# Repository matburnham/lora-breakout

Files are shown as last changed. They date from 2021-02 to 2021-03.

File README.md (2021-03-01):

# DRF1278F and XL1278-SMT LoRa breakout board

A somewhat 'universal' breakout board to adapt Dorji DRF1278F and XL1278-SMT modules to standard 0.1" matrix breadboard or stripboard format.

# Module identification

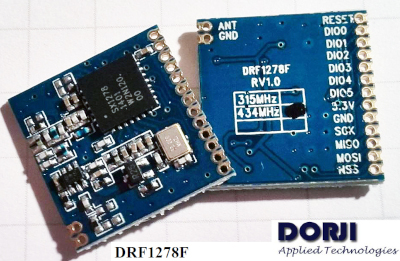
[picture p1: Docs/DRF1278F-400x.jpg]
DRF1278F


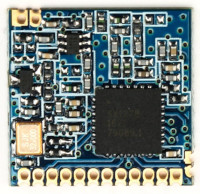
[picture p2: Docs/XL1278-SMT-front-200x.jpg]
XL1278-SMT-front
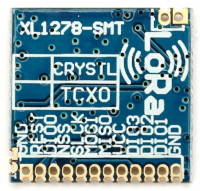
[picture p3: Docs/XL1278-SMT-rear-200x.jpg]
XL1278-SMT-back
 

Note: while the DRF1278F and XL1278-SMT boards look similar, the pinouts are significantly different.

## Confusion

There is a lot of confusion between Ebay and AliExpress sellers alike. One ebay seller even showing photos of both types of boards on the same listing. So check carefully, or use what you're given with this either/or breakout.

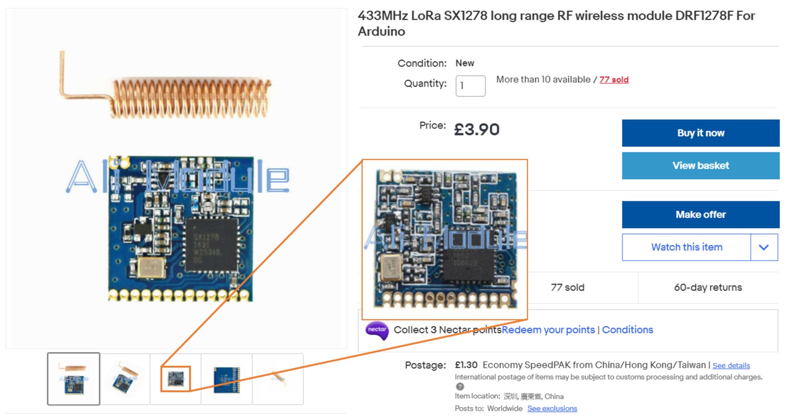
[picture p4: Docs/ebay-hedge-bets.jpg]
Ebay screenshot


## Documentation

CI/CD documentation generation 

TODO: links to generated documentation, etc.

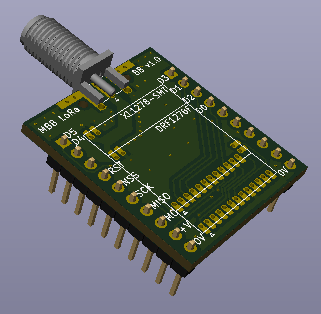
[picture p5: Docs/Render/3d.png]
3D render

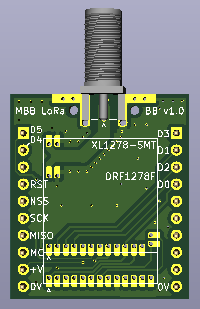
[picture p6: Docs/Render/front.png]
Front render

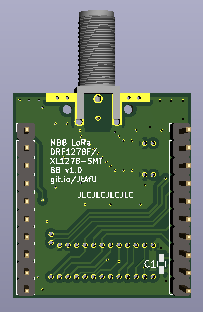
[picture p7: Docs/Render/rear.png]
Rear render


# Libraries

* KiCad symbol and footprint libraries for DRF1278F and XL1278-SMT for KiCad are at [kicad-libs](https://github.com/matburnham/kicad-libs)

# References

* Inspired by Stuart Robinson's Breadboard Friendly DRF1278 Board [Tindie](https://www.tindie.com/products/stuartsprojects/breadboard-friendly-board-for-dorji-drf1278-module/) | [GitHub](https://github.com/StuartsProjects/Devices/tree/master/Breadboard%20Friendly%20DRF1278%20Board)

* [Dorji DRF1278F datasheet](http://www.dorji.com/docs/data/DRF1278F.pdf) | [respository copy](Docs/DRF1278F.pdf)
* Closest information to a [XL1278-SMT datasheet](http://www.hr-wt.com/html_products/XL1278-SMT-59.html) | [respository screenshot](Docs/screencapture-hr-wt-html-products-XL1278-SMT-59-html-2021-02-26-15_49_33.png)

* [A Review of the Mini SX1278 LoRa Transceiver Module](https://www.electroschematics.com/rf-radio-frequency/)

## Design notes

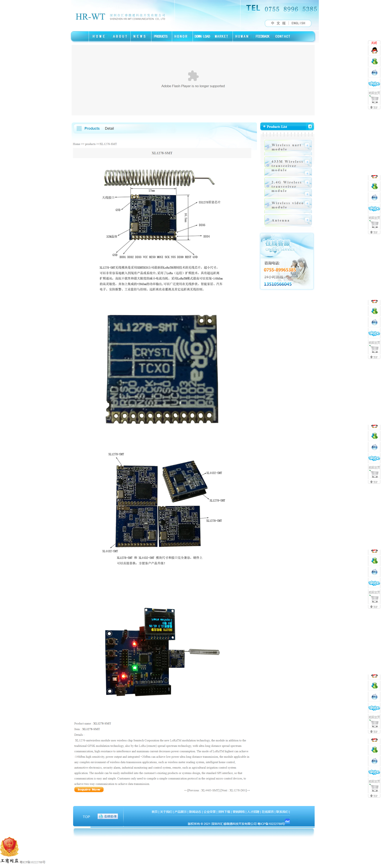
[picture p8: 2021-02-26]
Docs/screencapture-hr-wt-html-products-XL1278-SMT-59-html-2021-02-26-15_49_33.png

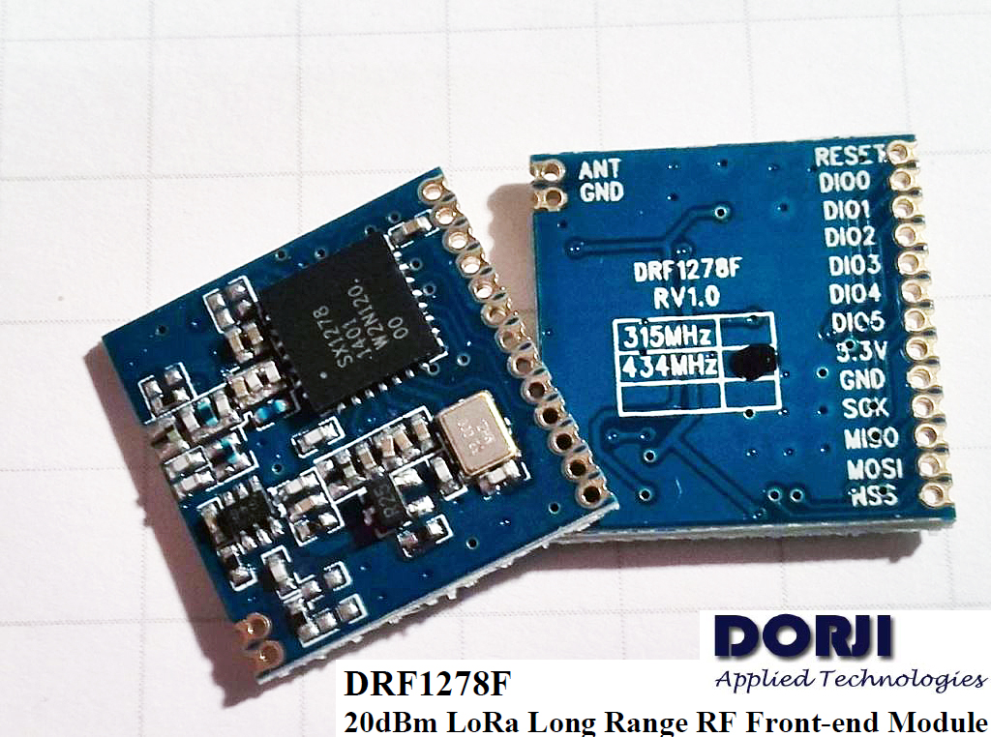
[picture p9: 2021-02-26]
Docs/DRF1278F.jpg

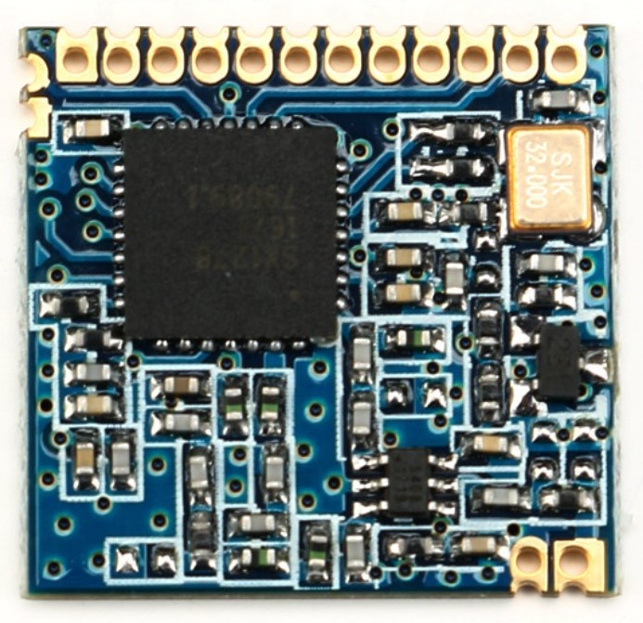
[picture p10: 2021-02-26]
Docs/XL1278-SMT-front.jpg

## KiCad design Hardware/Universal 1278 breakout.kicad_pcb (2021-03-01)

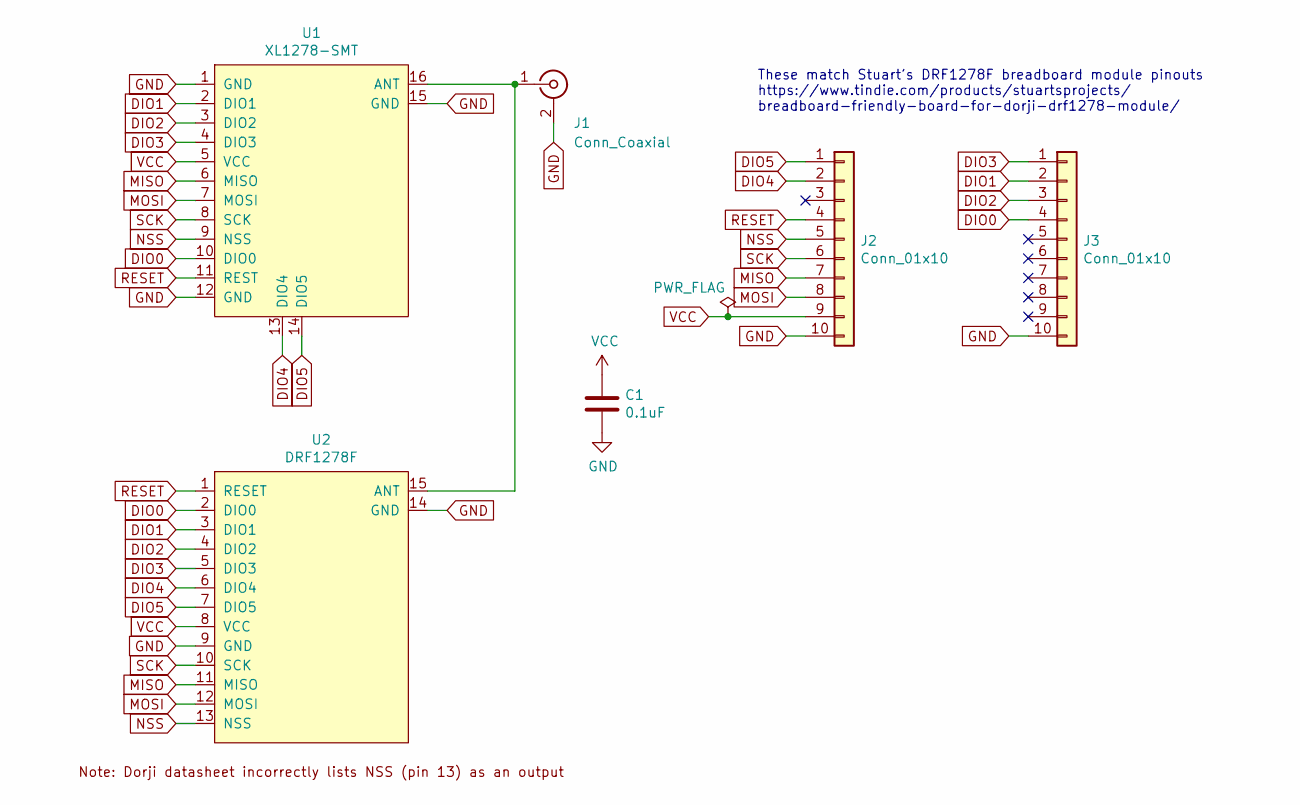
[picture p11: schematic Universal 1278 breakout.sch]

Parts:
C1: 0.1uF; C_0603_HandSoldering
J1: Conn_Coaxial; SMA_EdgeMount_Holes
J2, J3: Conn_01x10; PinHeader_1x10_P2.54mm_Vertical
U1: XL1278-SMT
U2: DRF1278F

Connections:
DIO0: J3.4, U1.10 (DIO0), U2.2 (DIO0)
DIO1: J3.2, U1.2 (DIO1), U2.3 (DIO1)
DIO2: J3.3, U1.3 (DIO2), U2.4 (DIO2)
DIO3: J3.1, U1.4 (DIO3), U2.5 (DIO3)
DIO4: J2.2, U1.13 (DIO4), U2.6 (DIO4)
DIO5: J2.1, U1.14 (DIO5), U2.7 (DIO5)
GND: C1.2, J1.2 (Ext), J2.10, J3.10, U1.1 (GND), U1.12 (GND), U1.15 (GND), U2.9 (GND), U2.14 (GND)
MISO: J2.7, U1.6 (MISO), U2.11 (MISO)
MOSI: J2.8, U1.7 (MOSI), U2.12 (MOSI)
NSS: J2.5, U1.9 (NSS), U2.13 (NSS)
unnamed: J1.1 (In), U1.16 (ANT), U2.15 (ANT)
RESET: J2.4, U1.11 (REST), U2.1 (RESET)
SCK: J2.6, U1.8 (SCK), U2.10 (SCK)
VCC: C1.1, J2.9, U1.5 (VCC), U2.8 (VCC)

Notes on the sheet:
These match Stuart's DRF1278F breadboard module pinouts https://www.tindie.com/products/stuartsprojects/ breadboard-friendly-board-for-dorji-drf1278-module/

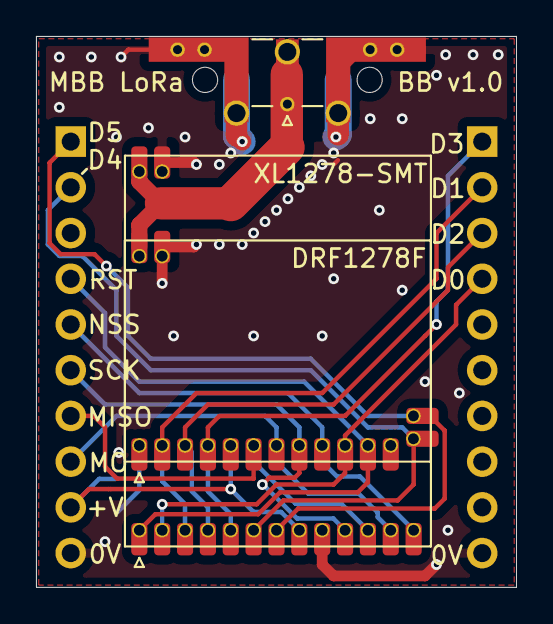
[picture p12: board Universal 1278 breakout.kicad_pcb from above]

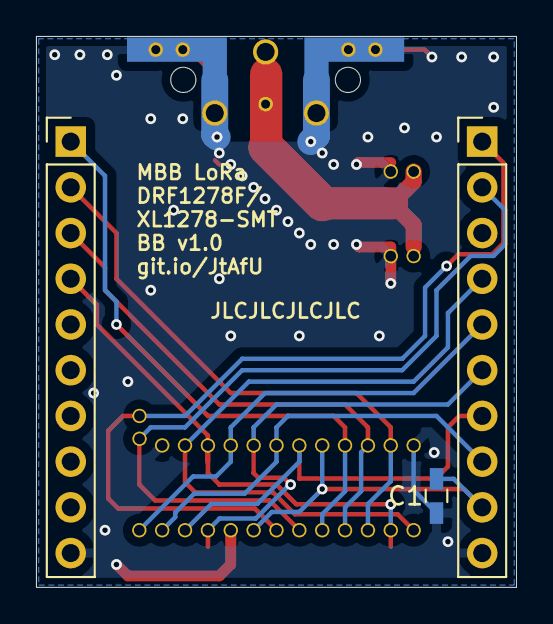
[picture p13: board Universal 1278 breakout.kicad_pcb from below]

Board: 2 copper layers, 26.7 x 30.6 mm, 6 parts (3 on the bottom side), 14 nets.

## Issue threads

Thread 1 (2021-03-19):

PCB layout issues

matburnham, 2021-03-19:
Issues noted from first batch of PCBs from JLCPCB:
- Chip identifier silkscreen text missing - was it on the right layer, was the same on another layer? Might be the library.
- Could have a smaller font for JLC ID on breakout boards.

Also note matburnham/kicad-libs#1 footprint issues which should be fixed and pulled in.

matburnham, 2021-03-19:
Seems some of the silkscreen text didn't make it into the silkscreen Gerber:

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

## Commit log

2021-02-26 Initial commit of board to get GitHub Actions, etc. up and running and shelve project before doing final pieces (ground pour, antenna holes, etc.)
    [Universal 1278 breakout.kicad_pcb, Universal 1278 breakout.sch]
2021-02-26 Can't find PCB files - does it even need the optional parameters?
2021-02-26 Try ** to find PCB files
2021-02-26 Fix (most) DRC errors.
    [Universal 1278 breakout.kicad_pcb, Universal 1278 breakout.sch]
2021-02-26 Ground pour. All DRC errors fixed except courtyards. Ignore courtyard warnings.
    [Universal 1278 breakout.kicad_pcb]
2021-02-26 Revert global filter that can't be there in the .yml Try turning off courtyard prohibition in project and see if CI picks this up instead.
    [Universal 1278 breakout.kicad_pcb]
2021-02-26 Fix all DRC violations - missing connections
    [Universal 1278 breakout.kicad_pcb]
2021-02-26 Add Cmts.User layer
    [Universal 1278 breakout.kicad_pcb]
2021-02-27 Various updates.
    [Universal 1278 breakout.kicad_pcb, Universal 1278 breakout.sch]
2021-02-27 Further updates
    [Universal 1278 breakout.kicad_pcb, Universal 1278 breakout.sch]
2021-03-01 Fix antenna ground connections
    [Universal 1278 breakout.kicad_pcb]
2021-03-01 Fix more grounds.
    [Universal 1278 breakout.kicad_pcb]
